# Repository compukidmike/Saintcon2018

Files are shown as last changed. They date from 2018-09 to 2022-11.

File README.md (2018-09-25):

# Saintcon2018
Here's all the info you need about the 2018 Saintcon badge. You'll find badge building and flashing instructions as well as how to operate it. The Minibadges folder has info for minibadge makers.

NOTE: Female headers will be provided with the main badge this year, so minbadge makers do not need to provide their own.

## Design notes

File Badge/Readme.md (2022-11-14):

# About the Badge
This year's badge features an ESP32 WiFi module running MicroPython. It has an 8x32 LED matrix display, 3 buttons, and 12 minibadge spots, as well as a rechargeable battery.
# Badge Instructions
## Building your badge
[BadgeBuildSheet.pdf](https://github.com/compukidmike/Saintcon2018/blob/master/Badge/BadgeBuildSheet.pdf) has instructions on how to assemble your badge
## Flashing your badge
You'll need some software to flash the code on your badge. 
The first thing you'll need is Python 3. This can be downloaded from https://www.python.org/downloads/
Once you have python installed, open a terminal/command prompt and run the following command: **pip install esptool**
You now have the tools you need to flash the code on your badge. Download **Saintcon2018.bin** from this github repository. 
Next, you will need to place the LOLIN D32 board into a mode where you can flash it's code.  To do this, you must pull GPIO pin 0 to ground.  This is best done by placing the LOLIN D32 board into a breadboard and pulling GPIO pin 0 to ground with a jumper wire.
Then, in a terminal window, navigate to the location of the badge firmware file, and run the following command, substituting the COM5 for the name of your badge serial port (this will vary depending on OS): **python esptool.py --port COM5 --baud 460800 write_flash --flash_size=detect 0 Saintcon2018.bin**

## Charging Your Badge
Simply use a microUSB cable to connect the badge to a USB power source (computer, phone charger, etc). This will power the badge as well as charge the battery.
The badge doesn't have an On/Off switch, so unplug the battery when you're not using it.

## Using Your Badge
The badge has 3 buttons labeled UP, DOWN, and SELECT. When first turned on, the badge is in display mode. Pressing the Up/Down buttons will cycle through the different displays. They are: SAINTCON, Custom Message, Hacker Challenge Score, Hacker Challenge ID.
 
Pressing Select will take you into the menu. The options here are: Brightness, Wifi Status, Wifi Config, Minibadges, Back. 
- Selecting Brightness will allow you to change the brightness of the LED matrix. 
- Selecting Wifi Status will show you if the wifi is connected or not. 
- Selecting Wifi Config will start the badge wifi configuration access point. In this mode, the display will show you the SSID and Password for the network that is being created by the badge. Connecting to that wifi network with your computer or phone will allow you to change badge settings like the wifi network that the badge connects to as well as the Custom Message. 
- Selecting Back will take you back to display mode.
 
Connecting your badge to a computer will allow you to do much more than the simple menu system allows, which brings us to...

## Editing Badge Code
To edit the badge code, I suggest an IDE called uPyCraft. It can be downloaded from http://docs.dfrobot.com/upycraft/ 
There are links on that page to tutorials on using the software.
One of the nice things about MicroPython is that the source code is all contained within the device, so you don't need to download the source to get started editing. uPyCraft can directly edit the files on the module.

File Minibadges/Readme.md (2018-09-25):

# Minibadges
The minbadge spec is here, along with eagle and kicad footprints: https://github.com/lukejenkins/minibadge  

Notes:
- 5V may not be exactly 5V. It'll probably be battery voltage (3.7-4.2V).  
- SPI *might* be connected, but don't plan on it. It gets complicated with more minibadges (one CS line per badge).  
- Please be conservative with power consumption on your minibadge. There will be a lot more minibadge spots on the badge this year, so battery life is a concern.  

If you have questions, contact me (compukidmike on twitter/slack/gmail)

## I2C Addresses
To avoid conflicts, here is the list of known minibadge I2C addresses.
To get your minibadge on this list, submit a pull request or send me a message (compukidmike on twitter/slack/gmail)
The Chip column is so I know which I2C chips to support in the main badge code (no promises, but I'm going to try to add support for as many as I can). If you're using a microcontroller, send me a spec on what I2C commands to send to it.

| Minibadge Name | Address | Chip |
| --- | --- | --- |
| hakinthebox.com | 0x01 | ATTiny |
| TBA | 0x29 | ATTiny |
| compukidmike | 0x40 | ATTiny |
| Professor Plum | 0x41 | ATTiny |
| TBA | 0x42 | ATTiny |
| TBA | 0x51 | M24C01 |
| TBA | 0x52 | M24C01 |
| bashNinja | 0x53 | M24C01 |
| TBA | 0x54 | M24C01 |

## I2C Message Protocol
This is a preliminary message protocol for minibadges. You are more than welcome to come up with other means of communication and write the supporting code for the main badge. This is just a starting point... if you have ideas on expanding this, please contact me.  

Since there isn’t an Interrupt line for the minibadges, the badge will poll each minibadge for a status byte (if supported by the minibadge).

Polling Message: 
- Will occur at regular intervals (multiple times per second) 
- Badge will send a standard read message (address with R/W bit set to R) 
- The byte that is returned by the minibadge will determine what happens next 
   - If byte is 0x00, status is empty, badge will end communication 
   - If byte is 0x01, status is Button Pressed (or similar input) (NOTE: this just passes button state to the badge. You'll have to write some code to do something with that data)
      - Next byte is button status (limited to 1 byte or 8 buttons)
   - If byte is 0x02, status is Text Message (for display on badge) (will be displayed for as long as it takes to scroll across the dislpay)
      - Next byte is text length (max 255 characters)
      - Next bytes are ASCII text
   - If byte is 0x03, status is Pixel Message (for display on badge)  (will be displayed for 2 seconds)
      - Next 32 bytes are display columns (Display is 8x32 pixels. 0,0 is bottom left corner. So first byte will fill the first column from bottom to top)
   - If byte is 0x04, status is Pixel Message with display time (this enables some animations) (for display on badge)
      - Next byte is time to display message (range is 0-255 x10 milliseconds, or 0-2.55 seconds in 10 millisecond increments). This will also be the amount of time before the badge polls the minibadge again for the next animation frame
      - Next 32 bytes are display columns (Display is 8x32 pixels. 0,0 is bottom left corner. So first byte will fill the first column from bottom to top)
   - If byte is 0x05, status is Custom Data (this allows your minibadge to send custom data to the badge that will require writing code for the badge to do something with it)
      - Next byte is length of data in bytes
      - Next bytes are custom data

Badge Event Message: 
- Will be sent to minibadges when they occur
- 0x01 - HC Score Updated
   - Next bytes(2) is score (16bit value, max score of 65535) 
- 0x02 - Brightness Change (will also be sent after power on) 
   - Next byte is brightness value (0-128) (Yes, 128. I know it's strange, but that's the brightness range for the LED matrix driver.)

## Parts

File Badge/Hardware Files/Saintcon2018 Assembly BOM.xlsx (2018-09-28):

Saintcon2018 1200PCS BOM
Click for Instructions on How to Create a BOM
Manufacturer | Manufacturer Part Number (required) | Designator (required) | Qty (required) | Description (required) | Case | SMD ,BGA,LCC,OR TH | Top/Bottom | points (number of contacts the IC has in each board) | Total points (number of contacts per BOM line has) | Comment
MCIGICM | MC-0603-RED | D1,D2,D3,D4,D5,D6,D7,D8,D9,D10,D11,D12,D13,D14,D15,D16,D17,D18,D19,D20,D21,D22,D23,D24,D25,D26,D27,D28,D29,D30,D31,D32,D33,D34,D35,D36,D37,D38,D39,D40,D41,D42,D43,D44,D45,D46,D47,D48,D49,D50,D51,D52,D53,D54,D55,D56,D57,D58,D59,D60,D61,D62,D63,D64,D65,D66,D67,D68,D69,D70,D71,D72,D73,D74,D75,D76,D77,D78,D79,D80,D81,D82,D83,D84,D85,D86,D87,D88,D89,D90,D91,D92,D93,D94,D95,D96,D97,D98,D99,D100,D101,D102,D103,D104,D105,D106,D107,D108,D109,D110,D111,D112,D113,D114,D115,D116,D117,D118,D119,D120,D121,D122,D123,D124,D125,D126,D127,D128,D129,D130,D131,D132,D133,D134,D135,D136,D137,D138,D139,D140,D141,D142,D143,D144,D145,D146,D147,D148,D149,D150,D151,D152,D153,D154,D155,D156,D157,D158,D159,D160,D161,D162,D163,D164,D165,D166,D167,D168,D169,D170,D171,D172,D173,D174,D175,D176,D177,D178,D179,D180,D181,D182,D183,D184,D185,D186,D187,D188,D189,D190,D191,D192,D193,D194,D195,D196,D197,D198,D199,D200,D201,D202,D203,D204,D205,D206,D207,D208,D209,D210,D211,D212,D213,D214,D215,D216,D217,D218,D219,D220,D221,D222,D223,D224,D225,D226,D227,D228,D229,D230,D231,D232,D233,D234,D235,D236,D237,D238,D239,D240,D241,D242,D243,D244,D245,D246,D247,D248,D249,D250,D251,D252,D253,D254,D255,D256 | 256 | Red LED 0603 | 0603 | SMD | Top | 2 | 512
ISSI | IS31FL3730-QFLS2-TR | U2,U3 | 2 | IC MATRIX LED DRIVER AUDIO 24QFN | QFN24 | SMD | Top | 24 | 48
Samsung Electro-Mechanics | CL10A105KP8NNNC | C1,C2,C9,C12,C13 | 5 | CAP CER 1UF 10V X5R 0603 | 0603 | SMD | Top | 2 | 10 | Generic Substitue is OK
Samsung Electro-Mechanics | CL10B104KB8NNNC | C3,C4,C10 | 3 | CAP CER 0.1UF 50V X7R 0603 | 0603 | SMD | Top | 2 | 6 | Generic Substitue is OK
Nichion | UWR1A101MCL1GB | C11 | 1 | CAP ALUM 100UF 20% 10V SMD | Radial, Can - SMD | SMD | Top | 2 | 2
Yaego | RC0603JR-07100KL | R3,R6,R7 | 3 | RES SMD 100K OHM 5% 1/10W 0603 | 0603 | SMD | Top | 2 | 6 | Generic Substitue is OK
Yaego | RC0603JR-074K7L | R1,R2,R4,R5 | 4 | RES SMD 4.7K OHM 5% 1/10W 0603 | 0603 | SMD | Top | 2 | 8 | Generic Substitue is OK
Diodes Incorporated | AP22802AW5-7 | U4 | 1 | IC LOAD SW PROGR SOT-25 | SC-74A, SOT-753 | SMD | Top | 5 | 5
Diodes Incorporated | AP2112K-3.3TRG1 | U5 | 1 | IC REG LINEAR 3.3V 600MA SOT25 | SC-74A, SOT-753 | SMD | Top | 5 | 5
C&K | PTS645SM43SMTR92 LFS | SW1,SW2,SW3 | 3 | SWITCH TACTILE SPST-NO 0.05A 12V | Gull Wing | SMD | Top | 4 | 12
DO NOT POPULATE | DO NOT POPULATE | J7,J6,J1,J2,J3,J4,J5,J8,J9,J10,J11,J12 | 12 | DO NOT POPULATE | DO NOT POPULATE | DO NOT POPULATE | Top | 0 | 0
DO NOT POPULATE | DO NOT POPULATE | U1 | 1 | DO NOT POPULATE | DO NOT POPULATE | DO NOT POPULATE | Top | 0 | 0

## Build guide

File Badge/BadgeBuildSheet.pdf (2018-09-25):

# Saintcon 2018 Badge Build Instructions

Most of the badge parts have already been soldered for you. The only things you need to solder are the headers for the main controller and the minibadges.

Step 1: Pick your headers. The HHC has 5 colors to choose from, so mix and match to make your badge uniquely yours! Available colors are: Red, Green, Blue, Yellow, and Black.
Step 2: Place headers on the Header Soldering Jig. This jig will hold all the headers straight to make it easier for you to solder your badge. Place your badge face-down on the headers and solder them all.

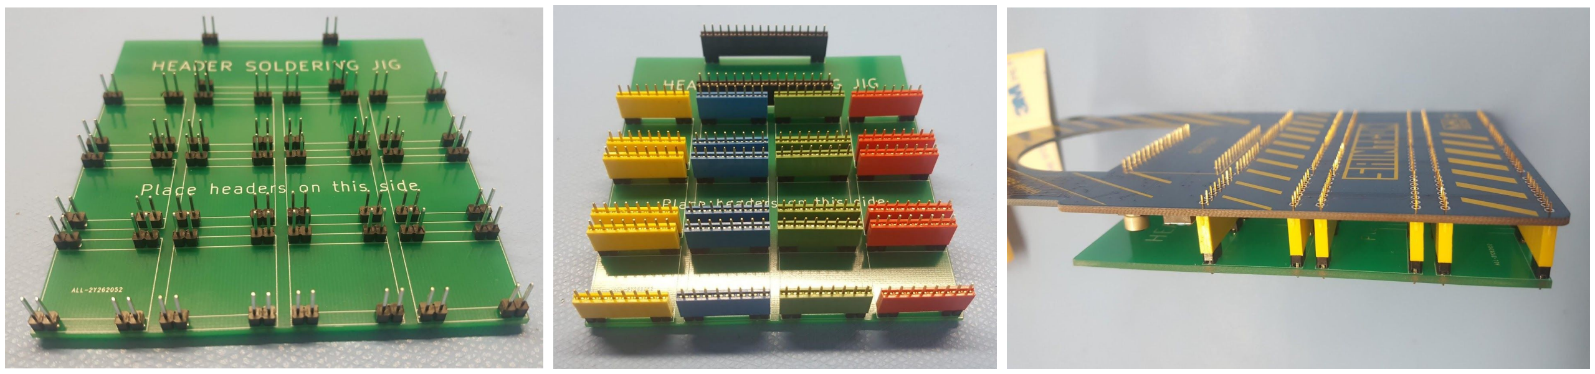
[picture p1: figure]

Step 3: Solder the ESP32. The module comes with 2 16pin headers. Plug them into the headers on the front of your board and then put the ESP32 on top. Pay close attention to orientation of the module. There are markings on the badge that you can match up to the module. Solder all the pins on the ESP32.

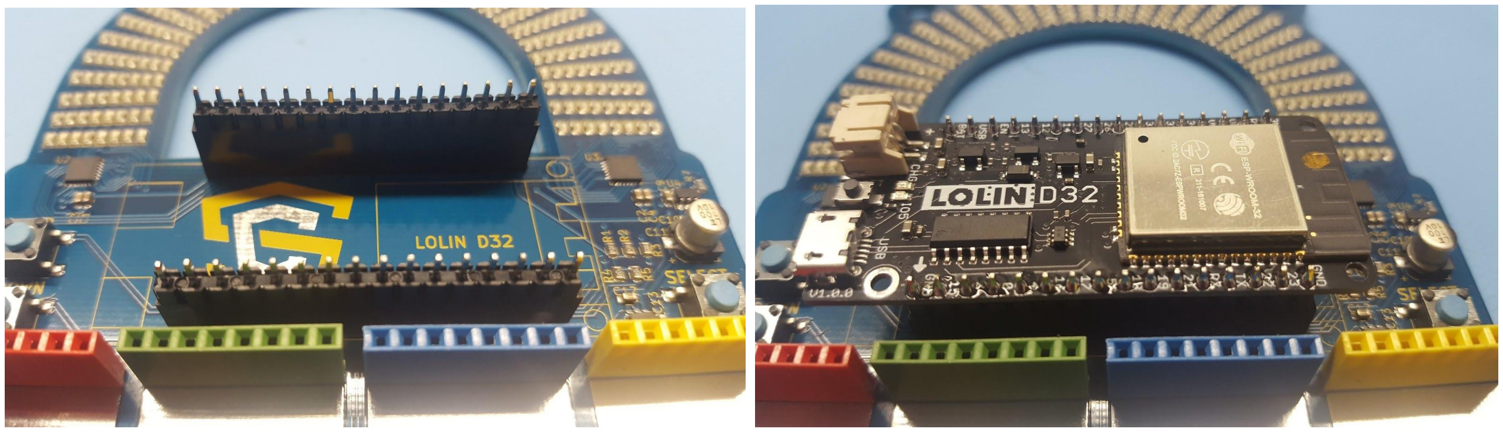
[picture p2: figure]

Step 4: Attach the plastic back plate. Remove the paper covering from both sides of the plastic. Test-fit it on the back of the badge. It can only fit one way, so if it doesn’t fit, try flipping it over. Now grab a couple strips of double-sided tape and stick the plastic sheet to the back of the badge.

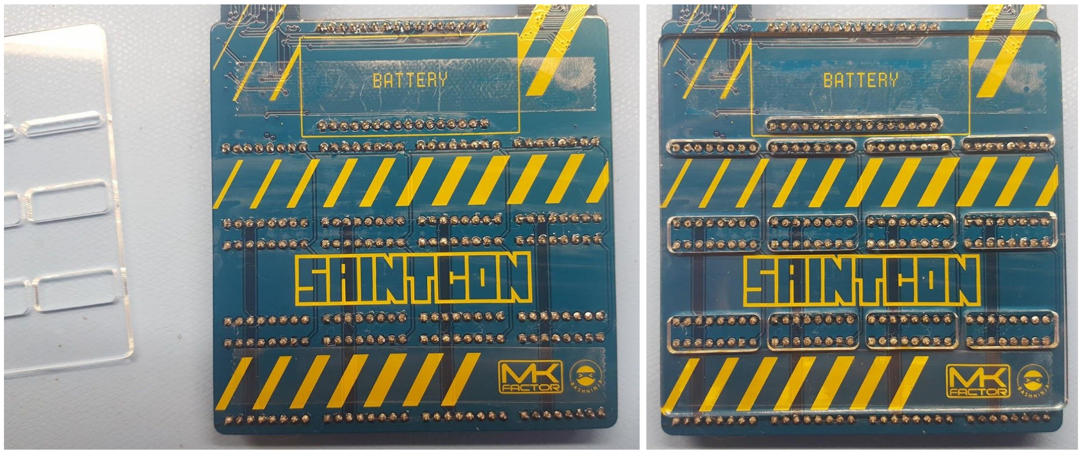
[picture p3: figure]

Step 5: Mount the battery. Using the sticky pad in your kit, attach the battery to the back of the badge, making sure the connector comes out the top-right corner of the battery.

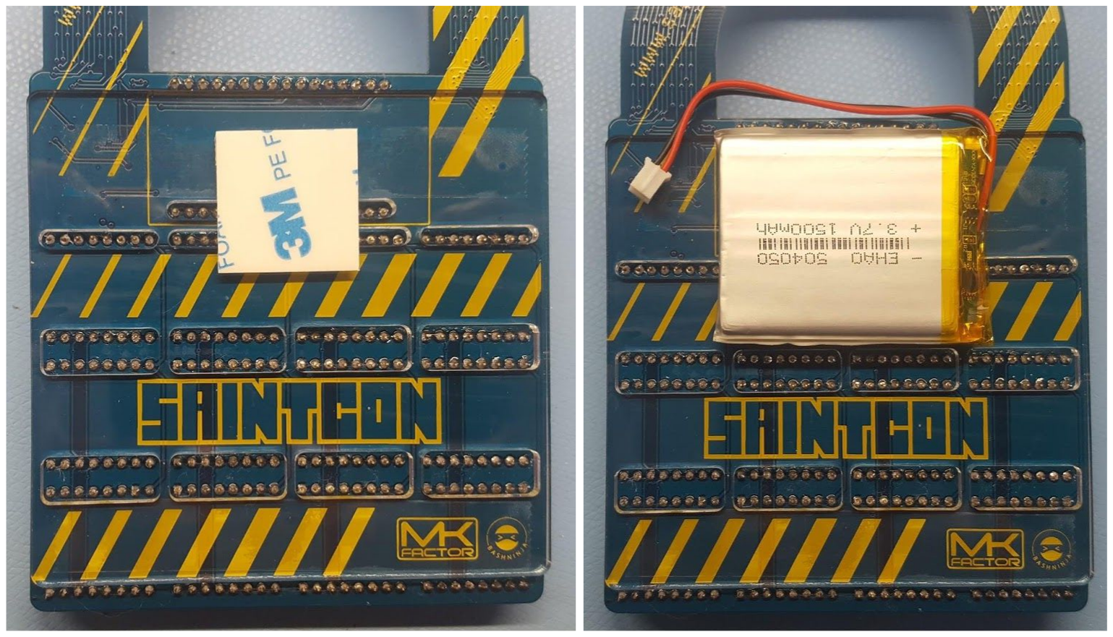
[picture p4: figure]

Step 6: Connect the battery. If all went well, your badge should light up! If it doesn’t, there are lots of talented staff members at the HHC that can help you out.

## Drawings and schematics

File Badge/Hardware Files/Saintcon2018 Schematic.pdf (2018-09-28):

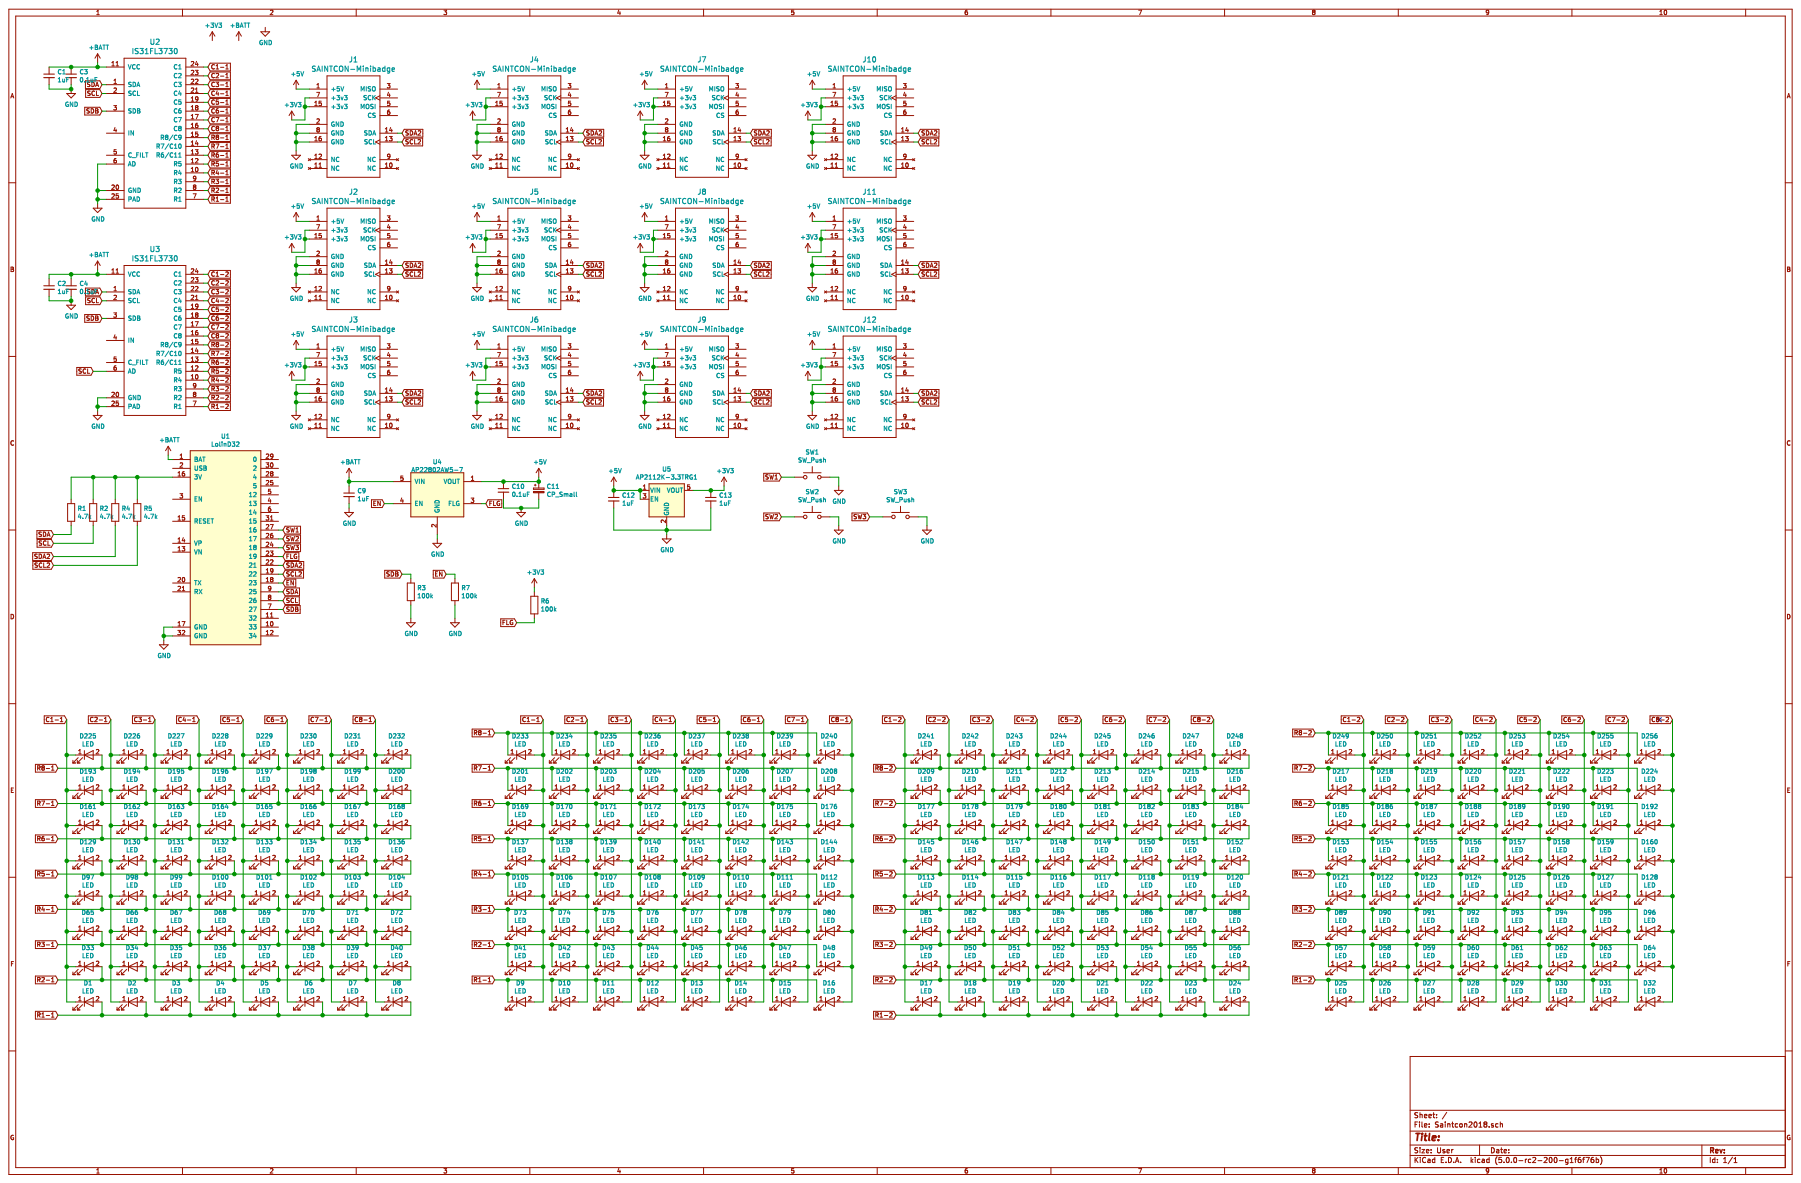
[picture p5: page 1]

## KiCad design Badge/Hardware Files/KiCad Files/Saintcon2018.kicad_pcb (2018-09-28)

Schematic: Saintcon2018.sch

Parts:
C1, C2, C9, C12, C13: 1uF; C_0603
C3, C4, C10: 0.1uF; C_0603
C11: CP_Small; CP_Elec_5x5.3
D1, D2, D3, D4, D5, D6, D7, D8, D9, D10, D11, D12, D13, D14, D15, D16, D17, D18, D19, D20, D21, D22, D23, D24, D25, D26, D27, D28, D29, D30, D31, D32, D33, D34, D35, D36, D37, D38, D39, D40, D41, D42, D43, D44, D45, D46, D47, D48, D49, D50, D51, D52, D53, D54, D55, D56, D57, D58, D59, D60, D61, D62, D63, D64, D65, D66, D67, D68, D69, D70, D71, D72, D73, D74, D75, D76, D77, D78, D79, D80, D81, D82, D83, D84, D85, D86, D87, D88, D89, D90, D91, D92, D93, D94, D95, D96, D97, D98, D99, D100, D101, D102, D103, D104, D105, D106, D107, D108, D109, D110, D111, D112, D113, D114, D115, D116, D117, D118, D119, D120, D121, D122, D123, D124, D125, D126, D127, D128, D129, D130, D131, D132, D133, D134, D135, D136, D137, D138, D139, D140, D141, D142, D143, D144, D145, D146, D147, D148, D149, D150, D151, D152, D153, D154, D155, D156, D157, D158, D159, D160, D161, D162, D163, D164, D165, D166, D167, D168, D169, D170, D171, D172, D173, D174, D175, D176, D177, D178, D179, D180, D181, D182, D183, D184, D185, D186, D187, D188, D189, D190, D191, D192, D193, D194, D195, D196, D197, D198, D199, D200, D201, D202, D203, D204, D205, D206, D207, D208, D209, D210, D211, D212, D213, D214, D215, D216, D217, D218, D219, D220, D221, D222, D223, D224, D225, D226, D227, D228, D229, D230, D231, D232, D233, D234, D235, D236, D237, D238, D239, D240, D241, D242, D243, D244, D245, D246, D247, D248, D249, D250, D251, D252, D253, D254, D255, D256: LED; LED_0603_1608Metric
J1, J2, J3, J4, J5, J6, J7, J8, J9, J10, J11, J12: SAINTCON-Minibadge; SAINTCON-Minibadge-Shiny
R1, R2, R4, R5: 4.7k; R_0603
R3, R6, R7: 100k; R_0603
SW1, SW2, SW3: SW_Push; SW_SPST_PTS645
U1: LolinD32; Lolin D32
U2, U3: IS31FL3730; QFN-24_EP_4x4_Pitch0.5mm
U4: AP22802AW5-7; SOT-23-5
U5: AP2112K-3.3TRG1; SOT-23-5

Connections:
+3V3: C13.1, J1.7, J1.15, J2.7, J2.15, J3.7, J3.15, J4.7, J4.15, J5.7, J5.15, J6.7, J6.15, J7.7, J7.15, J8.7, J8.15, J9.7, J9.15, J10.7, J10.15, J11.7, J11.15, J12.7, J12.15, R6.1, U5.5 (VOUT)
+5V: C10.1, C11.1, C12.1, J1.1, J2.1, J3.1, J4.1, J5.1, J6.1, J7.1, J8.1, J9.1, J10.1, J11.1, J12.1, U4.1 (VOUT), U5.1 (VIN), U5.3 (EN)
+BATT: C1.1, C2.1, C3.1, C4.1, C9.1, U1.1 (BAT), U2.11 (VCC), U3.11 (VCC), U4.5 (VIN)
C1-1: D1.1 (K), D9.2 (A), D33.1 (K), D41.2 (A), D65.1 (K), D73.2 (A), D97.1 (K), D105.2 (A), D129.1 (K), D137.2 (A), D161.1 (K), D169.2 (A), D193.1 (K), D201.2 (A), D225.1 (K), D233.2 (A), U2.24 (C1)
C1-2: D17.1 (K), D25.2 (A), D49.1 (K), D57.2 (A), D81.1 (K), D89.2 (A), D113.1 (K), D121.2 (A), D145.1 (K), D153.2 (A), D177.1 (K), D185.2 (A), D209.1 (K), D217.2 (A), D241.1 (K), D249.2 (A), U3.24 (C1)
C2-1: D2.1 (K), D10.2 (A), D34.1 (K), D42.2 (A), D66.1 (K), D74.2 (A), D98.1 (K), D106.2 (A), D130.1 (K), D138.2 (A), D162.1 (K), D170.2 (A), D194.1 (K), D202.2 (A), D226.1 (K), D234.2 (A), U2.23 (C2)
C2-2: D18.1 (K), D26.2 (A), D50.1 (K), D58.2 (A), D82.1 (K), D90.2 (A), D114.1 (K), D122.2 (A), D146.1 (K), D154.2 (A), D178.1 (K), D186.2 (A), D210.1 (K), D218.2 (A), D242.1 (K), D250.2 (A), U3.23 (C2)
C3-1: D3.1 (K), D11.2 (A), D35.1 (K), D43.2 (A), D67.1 (K), D75.2 (A), D99.1 (K), D107.2 (A), D131.1 (K), D139.2 (A), D163.1 (K), D171.2 (A), D195.1 (K), D203.2 (A), D227.1 (K), D235.2 (A), U2.22 (C3)
C3-2: D19.1 (K), D27.2 (A), D51.1 (K), D59.2 (A), D83.1 (K), D91.2 (A), D115.1 (K), D123.2 (A), D147.1 (K), D155.2 (A), D179.1 (K), D187.2 (A), D211.1 (K), D219.2 (A), D243.1 (K), D251.2 (A), U3.22 (C3)
C4-1: D4.1 (K), D12.2 (A), D36.1 (K), D44.2 (A), D68.1 (K), D76.2 (A), D100.1 (K), D108.2 (A), D132.1 (K), D140.2 (A), D164.1 (K), D172.2 (A), D196.1 (K), D204.2 (A), D228.1 (K), D236.2 (A), U2.21 (C4)
C4-2: D20.1 (K), D28.2 (A), D52.1 (K), D60.2 (A), D84.1 (K), D92.2 (A), D116.1 (K), D124.2 (A), D148.1 (K), D156.2 (A), D180.1 (K), D188.2 (A), D212.1 (K), D220.2 (A), D244.1 (K), D252.2 (A), U3.21 (C4)
C5-1: D5.1 (K), D13.2 (A), D37.1 (K), D45.2 (A), D69.1 (K), D77.2 (A), D101.1 (K), D109.2 (A), D133.1 (K), D141.2 (A), D165.1 (K), D173.2 (A), D197.1 (K), D205.2 (A), D229.1 (K), D237.2 (A), U2.19 (C5)
C5-2: D21.1 (K), D29.2 (A), D53.1 (K), D61.2 (A), D85.1 (K), D93.2 (A), D117.1 (K), D125.2 (A), D149.1 (K), D157.2 (A), D181.1 (K), D189.2 (A), D213.1 (K), D221.2 (A), D245.1 (K), D253.2 (A), U3.19 (C5)
C6-1: D6.1 (K), D14.2 (A), D38.1 (K), D46.2 (A), D70.1 (K), D78.2 (A), D102.1 (K), D110.2 (A), D134.1 (K), D142.2 (A), D166.1 (K), D174.2 (A), D198.1 (K), D206.2 (A), D230.1 (K), D238.2 (A), U2.18 (C6)
C6-2: D22.1 (K), D30.2 (A), D54.1 (K), D62.2 (A), D86.1 (K), D94.2 (A), D118.1 (K), D126.2 (A), D150.1 (K), D158.2 (A), D182.1 (K), D190.2 (A), D214.1 (K), D222.2 (A), D246.1 (K), D254.2 (A), U3.18 (C6)
C7-1: D7.1 (K), D15.2 (A), D39.1 (K), D47.2 (A), D71.1 (K), D79.2 (A), D103.1 (K), D111.2 (A), D135.1 (K), D143.2 (A), D167.1 (K), D175.2 (A), D199.1 (K), D207.2 (A), D231.1 (K), D239.2 (A), U2.17 (C7)
C7-2: D23.1 (K), D31.2 (A), D55.1 (K), D63.2 (A), D87.1 (K), D95.2 (A), D119.1 (K), D127.2 (A), D151.1 (K), D159.2 (A), D183.1 (K), D191.2 (A), D215.1 (K), D223.2 (A), D247.1 (K), D255.2 (A), U3.17 (C7)
C8-1: D8.1 (K), D16.2 (A), D40.1 (K), D48.2 (A), D72.1 (K), D80.2 (A), D104.1 (K), D112.2 (A), D136.1 (K), D144.2 (A), D168.1 (K), D176.2 (A), D200.1 (K), D208.2 (A), D232.1 (K), D240.2 (A), U2.16 (C8)
C8-2: D24.1 (K), D32.2 (A), D56.1 (K), D64.2 (A), D88.1 (K), D96.2 (A), D120.1 (K), D128.2 (A), D152.1 (K), D160.2 (A), D184.1 (K), D192.2 (A), D216.1 (K), D224.2 (A), D248.1 (K), D256.2 (A), U3.16 (C8)
EN: R7.1, U1.18 (23), U4.4 (EN)
FLG: R6.2, U1.23 (19), U4.3 (FLG)
GND: C1.2, C2.2, C3.2, C4.2, C9.2, C10.2, C11.2, C12.2, C13.2, J1.2, J1.8, J1.16, J2.2, J2.8, J2.16, J3.2, J3.8, J3.16, J4.2, J4.8, J4.16, J5.2, J5.8, J5.16, J6.2, J6.8, J6.16, J7.2, J7.8, J7.16, J8.2, J8.8, J8.16, J9.2, J9.8, J9.16, J10.2, J10.8, J10.16, J11.2, J11.8, J11.16, J12.2, J12.8, J12.16, R3.2, R7.2, SW1.2, SW2.2, SW3.2, U1.17 (GND), U1.32 (GND), U2.6 (AD), U2.20 (GND), U2.25 (PAD), U3.20 (GND), U3.25 (PAD), U4.2 (GND), U5.2 (GND)
unnamed: R1.1, R2.1, R4.1, R5.1, U1.16 (3V)
R1-1: D1.2 (A), D2.2 (A), D3.2 (A), D4.2 (A), D5.2 (A), D6.2 (A), D7.2 (A), D8.2 (A), D9.1 (K), D10.1 (K), D11.1 (K), D12.1 (K), D13.1 (K), D14.1 (K), D15.1 (K), D16.1 (K), U2.7 (R1)
R1-2: D17.2 (A), D18.2 (A), D19.2 (A), D20.2 (A), D21.2 (A), D22.2 (A), D23.2 (A), D24.2 (A), D25.1 (K), D26.1 (K), D27.1 (K), D28.1 (K), D29.1 (K), D30.1 (K), D31.1 (K), D32.1 (K), U3.7 (R1)
R2-1: D33.2 (A), D34.2 (A), D35.2 (A), D36.2 (A), D37.2 (A), D38.2 (A), D39.2 (A), D40.2 (A), D41.1 (K), D42.1 (K), D43.1 (K), D44.1 (K), D45.1 (K), D46.1 (K), D47.1 (K), D48.1 (K), U2.8 (R2)
R2-2: D49.2 (A), D50.2 (A), D51.2 (A), D52.2 (A), D53.2 (A), D54.2 (A), D55.2 (A), D56.2 (A), D57.1 (K), D58.1 (K), D59.1 (K), D60.1 (K), D61.1 (K), D62.1 (K), D63.1 (K), D64.1 (K), U3.8 (R2)
R3-1: D65.2 (A), D66.2 (A), D67.2 (A), D68.2 (A), D69.2 (A), D70.2 (A), D71.2 (A), D72.2 (A), D73.1 (K), D74.1 (K), D75.1 (K), D76.1 (K), D77.1 (K), D78.1 (K), D79.1 (K), D80.1 (K), U2.9 (R3)
R3-2: D81.2 (A), D82.2 (A), D83.2 (A), D84.2 (A), D85.2 (A), D86.2 (A), D87.2 (A), D88.2 (A), D89.1 (K), D90.1 (K), D91.1 (K), D92.1 (K), D93.1 (K), D94.1 (K), D95.1 (K), D96.1 (K), U3.9 (R3)
R4-1: D97.2 (A), D98.2 (A), D99.2 (A), D100.2 (A), D101.2 (A), D102.2 (A), D103.2 (A), D104.2 (A), D105.1 (K), D106.1 (K), D107.1 (K), D108.1 (K), D109.1 (K), D110.1 (K), D111.1 (K), D112.1 (K), U2.10 (R4)
R4-2: D113.2 (A), D114.2 (A), D115.2 (A), D116.2 (A), D117.2 (A), D118.2 (A), D119.2 (A), D120.2 (A), D121.1 (K), D122.1 (K), D123.1 (K), D124.1 (K), D125.1 (K), D126.1 (K), D127.1 (K), D128.1 (K), U3.10 (R4)
R5-1: D129.2 (A), D130.2 (A), D131.2 (A), D132.2 (A), D133.2 (A), D134.2 (A), D135.2 (A), D136.2 (A), D137.1 (K), D138.1 (K), D139.1 (K), D140.1 (K), D141.1 (K), D142.1 (K), D143.1 (K), D144.1 (K), U2.12 (R5)
R5-2: D145.2 (A), D146.2 (A), D147.2 (A), D148.2 (A), D149.2 (A), D150.2 (A), D151.2 (A), D152.2 (A), D153.1 (K), D154.1 (K), D155.1 (K), D156.1 (K), D157.1 (K), D158.1 (K), D159.1 (K), D160.1 (K), U3.12 (R5)
R6-1: D161.2 (A), D162.2 (A), D163.2 (A), D164.2 (A), D165.2 (A), D166.2 (A), D167.2 (A), D168.2 (A), D169.1 (K), D170.1 (K), D171.1 (K), D172.1 (K), D173.1 (K), D174.1 (K), D175.1 (K), D176.1 (K), U2.13 (R6/C11)
R6-2: D177.2 (A), D178.2 (A), D179.2 (A), D180.2 (A), D181.2 (A), D182.2 (A), D183.2 (A), D184.2 (A), D185.1 (K), D186.1 (K), D187.1 (K), D188.1 (K), D189.1 (K), D190.1 (K), D191.1 (K), D192.1 (K), U3.13 (R6/C11)
R7-1: D193.2 (A), D194.2 (A), D195.2 (A), D196.2 (A), D197.2 (A), D198.2 (A), D199.2 (A), D200.2 (A), D201.1 (K), D202.1 (K), D203.1 (K), D204.1 (K), D205.1 (K), D206.1 (K), D207.1 (K), D208.1 (K), U2.14 (R7/C10)
R7-2: D209.2 (A), D210.2 (A), D211.2 (A), D212.2 (A), D213.2 (A), D214.2 (A), D215.2 (A), D216.2 (A), D217.1 (K), D218.1 (K), D219.1 (K), D220.1 (K), D221.1 (K), D222.1 (K), D223.1 (K), D224.1 (K), U3.14 (R7/C10)
R8-1: D225.2 (A), D226.2 (A), D227.2 (A), D228.2 (A), D229.2 (A), D230.2 (A), D231.2 (A), D232.2 (A), D233.1 (K), D234.1 (K), D235.1 (K), D236.1 (K), D237.1 (K), D238.1 (K), D239.1 (K), D240.1 (K), U2.15 (R8/C9)
R8-2: D241.2 (A), D242.2 (A), D243.2 (A), D244.2 (A), D245.2 (A), D246.2 (A), D247.2 (A), D248.2 (A), D249.1 (K), D250.1 (K), D251.1 (K), D252.1 (K), D253.1 (K), D254.1 (K), D255.1 (K), D256.1 (K), U3.15 (R8/C9)
SCL: R2.2, U1.8 (26), U2.2 (SCL), U3.2 (SCL), U3.6 (AD)
SCL2: J1.13, J2.13, J3.13, J4.13, J5.13, J6.13, J7.13, J8.13, J9.13, J10.13, J11.13, J12.13, R5.2, U1.19 (22)
SDA: R1.2, U1.9 (25), U2.1 (SDA), U3.1 (SDA)
SDA2: J1.14, J2.14, J3.14, J4.14, J5.14, J6.14, J7.14, J8.14, J9.14, J10.14, J11.14, J12.14, R4.2, U1.22 (21)
SDB: R3.1, U1.7 (27), U2.3 (SDB), U3.3 (SDB)
SW1: SW1.1, U1.27 (16)
SW2: SW2.1, U1.26 (17)
SW3: SW3.1, U1.24 (18)

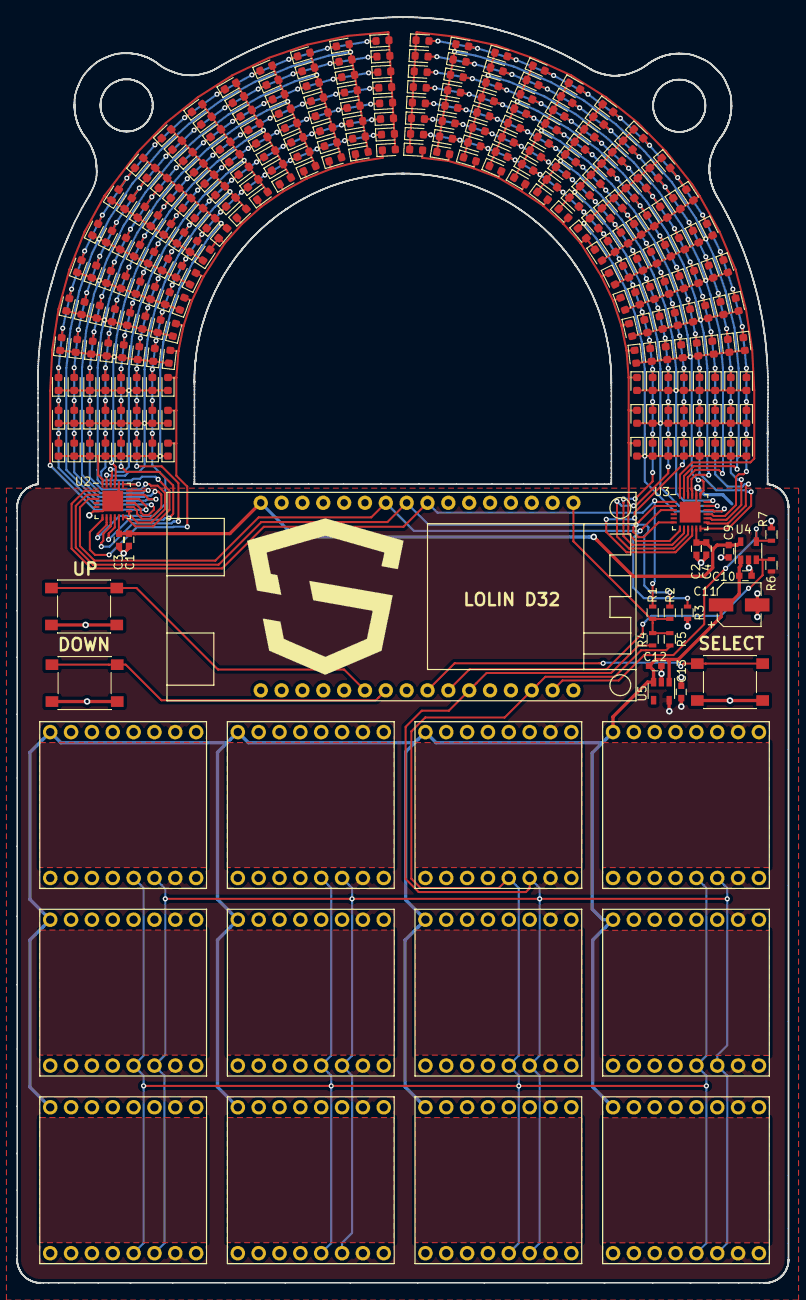
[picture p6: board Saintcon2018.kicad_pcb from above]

Board: 2 copper layers, 94.0 x 154.2 mm, 292 parts (0 on the bottom side), 47 nets.

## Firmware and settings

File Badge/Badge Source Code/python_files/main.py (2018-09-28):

#Saintcon2018 Badge Code
#by compukidmike and bashninja

#hardware platform: ESP32

import time
import machine
import matrix
import uasyncio as asyncio
from aswitch import Pushbutton

import configure
import wifi_config
import hc
import hcid as HCID

import _thread

hcid = HCID.getHCID()

hcidPassword = HCID.getPassword()

wifiConfigMode = 0
wifiMacAddr = HCID.getMac()
print("MAC Address: " + wifiMacAddr)
wifiConfigSSID = "SC_" + str(wifiMacAddr)[-5:-1]

ssid = ""


i2c = machine.I2C(scl=machine.Pin(26), sda=machine.Pin(25), freq=100000)
i2c2 = machine.I2C(scl=machine.Pin(22), sda=machine.Pin(21), freq=10000)

#Add minibadge I2C addresses to this list
I2CDeviceList = {0x01,0x29,0x40, 0x41, 0x42}
#I2CDeviceList = {0x01,0x40}
#Add minibadges with I2C EEPROMs to this list
I2CEEPROMList = {}

led = matrix.Matrix(i2c)
brightness = 32
displayUpdateDelay = 75
nextDisplayUpdateTime = 0
currentTicks = 0
animationCounter = 0

upPressed = 0
downPressed = 0
selectPressed = 0

displayState = 1
previousDisplayState = 1
displayMode = 0
currentAnimation = 0

userHandle = 'Test'
userHCScore = 0
userCustomMessage = 'Custom Message'

minibadgePreviousDisplayState = 0
minibadgeTextMessage = 'empty'
pixelDisplayData = bytearray(32)
pixelDisplayDelay = 2000


pwrEnable = machine.Pin(23, machine.Pin.OUT)
pwrEnable.value(1) #Turn on minbadge power

displayEnable = machine.Pin(27, machine.Pin.OUT)
displayEnable.value(1) #Enable matrix drivers

upPin = machine.Pin(16, machine.Pin.IN, machine.Pin.PULL_UP)
downPin = machine.Pin(17, machine.Pin.IN, machine.Pin.PULL_UP)
selectPin = machine.Pin(18, machine.Pin.IN, machine.Pin.PULL_UP)

#set LED matrix brightness
led.brightness(brightness)

#Send brightness to all minibadges
data = bytearray(3)
for x in I2CDeviceList:
  if x != 0x01:
    try:
      i2c2.start()
      data[0] = x<<1 
      data[1] = 0x02
      data[2] = brightness
      i2c2.write(data)
      i2c2.stop()
    except:
      pass
#print(i2c2.scan()) #Use this to debug I2C stuff


async def buttonPressed(button): #up=1,down=2,select=3
  global displayState
  if displayState != 18 and displayState != 19:
    switcher = {
      1: stateSaintcon,
      2: stateCustom,
      3: stateHCScore,
      4: stateHCID,
      5: stateBroadcast,
      6: stateMenuBrightness,
      7: stateMenuHandleEdit,
      8: stateMenuWifiStatus,
      9: stateMenuWifiConfig,
      10: stateMenuMinibadges,
      12: stateMenuBack,
      13: stateBrightness,
      14: stateHandleEdit,
      15: stateWifiStatus,
      16: stateWifiConfig,
      17: stateMinibadges
    }
    func = switcher.get(displayState)
    result = func(button)
    #print("state:", displayState)
  
  
def stateSaintcon(button): #1
  global displayState
  global userCustomMessage
  if(button == 1): #Up Button
    userCustomMessage = wifi_config.get_custom_message()
    displayState = 4 #Custom
  if(button == 2): #Down Button
    displayState = 2 #Handle
  if(button == 3): #Select Button
    displayState = 6 #MenuBrightness
    
def stateCustom(button): #2
  global displayState
  if(button == 1): #Up Button
    displayState = 1 #Saintcon
  if(button == 2): #Down Button
    displayState = 3 #HCScore
  if(button == 3): #Select Button
    displayState = 6 #MenuBrightness
    
def stateHCScore(button): #3
  global displayState
  global userCustomMessage
  if(button == 1): #Up Button
    displayState = 2 #Handle
  if(button == 2): #Down Button
    userCustomMessage = wifi_config.get_custom_message()
    displayState = 4 #Custom
  if(button == 3): #Select Button
    displayState = 6 #MenuBrightness
    
def stateHCID(button): #4
  global displayState
  if(button == 1): #Up Button
    displayState = 3 #HCScore
  if(button == 2): #Down Button
    displayState = 1 #Saintcon
  if(button == 3): #Select Button
    displayState = 6 #MenuBrightness
    
def stateBroadcast(button): #5
  global displayState
  global userCustomMessage
  if(button == 1): #Up Button
    userCustomMessage = wifi_config.get_custom_message()
    displayState = 4 #Custom
  if(button == 2): #Down Button
    displayState = 2 #Handle
  if(button == 3): #Select Button
    displayState = 6 #MenuBrightness
    
def stateMenuBrightness(button): #6
  global displayState
  if(button == 1): #Up Button
    displayState = 12 #MenuBack
  if(button == 2): #Down Button
    displayState = 8 #MenuHandleEdit
  if(button == 3): #Select Button
    displayState = 13 #Brightness

def stateMenuHandleEdit(button): #7
  #not implemented
  return

def stateMenuWifiStatus(button): #8
  global displayState
  global ssid
  if(button == 1): #Up Button
    displayState = 6 #MenuHandleEdit
  if(button == 2): #Down Button
    displayState = 9 #MenuWifiConfig
  if(button == 3): #Select Button
    ssid = wifi_config.get_ssid()
    displayState = 15 #WifiStatus
    
def stateMenuWifiConfig(button): #9
  global displayState
  global wifiConfigMode
  if(button == 1): #Up Button
    displayState = 8 #MenuWifiStatus
  if(button == 2): #Down Button
    displayState = 10 #MenuMinibadges
  if(button == 3): #Select Button
    displayState = 16 #WifiConfig
    wifiConfigMode = 1
    
def stateMenuMinibadges(button): #10
  global displayState
  if(button == 1): #Up Button
    displayState = 9 #MenuWifiConfig
  if(button == 2): #Down Button
    displayState = 12 #MenuBrightness
  if(button == 3): #Select Button
    displayState = 17 #Minibadges
    
def stateMenuBack(button): #12
  global displayState
  if(button == 1): #Up Button
    displayState = 10 #MenuMinibadges
  if(button == 2): #Down Button
    displayState = 6 #MenuBrightness
  if(button == 3): #Select Button
    displayState = 1 #Saintcon
    
def stateBrightness(button): #13
  global displayState
  global brightness
  if(button == 1): #Up Button
    brightness += 10
    if(brightness > 128):
      brightness = 128
  if(button == 2): #Down Button
    brightness -= 10
    if(brightness < 1):
      brightness = 1
  led.brightness(brightness)
  data = bytearray(3)
  for x in I2CDeviceList:
    if x != 0x01:
      try:
        i2c2.start()
        data[0] = x<<1 
        data[1] = 0x02
        data[2] = brightness
        i2c2.write(data)
        i2c2.stop()
      except:
        pass
  if(button == 3): #Select Button
    displayState = 6 #MenuBrightness
    
def stateHandleEdit(button): #14
  #not implemented
  return
    
def stateWifiStatus(button): #15
  global displayState
  if(button == 3): #Select Button
    displayState = 8 #MenuWifiStatus
    
def stateWifiConfig(button): #16
  global displayState
  if(button == 1): #Up Button
    displayState = 16
  if(button == 2): #Down Button
    displayState = 16
  if(button == 3): #Select Button
    displayState = 16 #MenuWifiConfig

def stateMinibadges(button): #17
  global displayState
  global displayEnable
  if(button == 1): #Up Button
    if(pwrEnable.value() == 1):
      pwrEnable.value(0)
    else:
      pwrEnable.value(1)
  if(button == 2): #Down Button
    if(pwrEnable.value() == 1):
      pwrEnable.value(0)
    else:
      pwrEnable.value(1)
  if(button == 3): #Select Button
    displayState = 10 #MenuMinibadges
    

async def updateDisplay():
  global animationCounter
  global scrollCounter
  global displayUpdateDelay
  global displayState
  global previousDisplayState
  global userHandle
  global userHCScore
  global userCustomMessage
  global minibadgeTextMessage
  global minibadgePreviousDisplayState
  global pixelDisplayData
  global pixelDisplayDelay
  global ssid
  
  while(True):
    if(previousDisplayState != displayState):
      previousDisplayState = displayState
      animationCounter = 0
    
    if(displayState == 1): #Saintcon
      animationCounter += 1
      if(animationCounter > 80):
        animationCounter = 0
      led.word("SAINTCON",32-animationCounter)
      
    
    if(displayState == 2): #Custom
      if((len(str(userCustomMessage)) * 6)-1 > 32):
        animationCounter += 1
        if(animationCounter > (len(str(userCustomMessage)) * 6)+32):
          animationCounter = 0
        led.word(str(userCustomMessage),32-animationCounter)
      else:
        led.word(str(userCustomMessage), int((32-(len(str(userCustomMessage))*6))/2))
        

    if(displayState == 3): #HCScore
      if((len(str(userHCScore)) * 6)-1 > 32):
        animationCounter += 1
        if(animationCounter > (len(str(userHCScore)) * 6)+32):
          animationCounter = 0
        led.word(str(userHCScore),32-animationCounter)
      else:
        led.word(str(userHCScore), int((32-(len(str(userHCScore))*6))/2))
        
    if(displayState == 4): #HCID
      message = "HCID: " + hcid
      if((len(message) * 6)-1 > 32):
        animationCounter += 1
        if(animationCounter > (len(message) * 6)+32):
          animationCounter = 0
        led.word(message,32-animationCounter)
      else:
        led.word(message, int((32-(len(message)*6))/2))
    
    #if(displayState == 5): #Broadcast
      #do something

    
    if(displayState == 6): #MenuBrightness
      animationCounter += 1
      if(animationCounter > (len("BRIGHTNESS") * 6)+32):
        animationCounter = 0
      led.word("BRIGHTNESS",32-animationCounter)
    
    if(displayState == 7): #MenuHandleEdit
      animationCounter += 1
      if(animationCounter > (len("HANDLE EDIT") * 6)+32):
        animationCounter = 0
      led.word("HANDLE EDIT",32-animationCounter)
    
    if(displayState == 8): #MenuWifiStatus
      animationCounter += 1
      if(animationCounter > (len("WIFI STATUS") * 6)+32):
        animationCounter = 0
      led.word("WIFI STATUS",32-animationCounter)
    
    if(displayState == 9): #MenuWifiConfig
      animationCounter += 1
      if(animationCounter > (len("WIFI CONFIG") * 6)+32):
        animationCounter = 0
      led.word("WIFI CONFIG",32-animationCounter)
    
    if(displayState == 10): #MenuMinibadges
      animationCounter += 1
      if(animationCounter > (len("MINIBADGES") * 6)+32):
        animationCounter = 0
      led.word("MINIBADGES",32-animationCounter)
    
    if(displayState == 12): #MenuBack
      animationCounter += 1
      if(animationCounter > (len("BACK") * 6)+32):
        animationCounter = 0
      led.word("BACK",32-animationCounter)
    
    if(displayState == 13): #Brightness
      global brightness
      led.word(str(brightness), int((32-(len(str(brightness))*6))/2))
    
    if(displayState == 14): #HandleEdit
      #not implemented
      return
    
    if(displayState == 15): #WifiStatus
      animationCounter += 1
      if wifi_config.is_wifi_connected():
        message = "CONNECTED TO: " + ssid + " IP: " + wifi_config.get_device_ip()
      else:
        message = "NOT CONNECTED"
      if(animationCounter > (len(message) * 6)+32):
        animationCounter = 0
      led.word(message,32-animationCounter)
    
    if(displayState == 16): #WifiConfig
      animationCounter += 1
      message = "SSID: " + wifiConfigSSID + " PASS: " + hcidPassword
      if(animationCounter > (len(message) * 6)+32):
        animationCounter = 0
      led.word(message,32-animationCounter)
    
    if(displayState == 17): #Minibadges
      if(pwrEnable.value() == 1):
        led.word("ON", int((32-(len("ON")*6))/2))
      else:
        led.word("OFF", int((32-(len("OFF")*6))/2))
    
    if(displayState == 18): #Minibadge Text Message
      animationCounter += 1
      if((len(minibadgeTextMessage) * 6)-1 > 32):
        
        if(animationCounter > (len(minibadgeTextMessage) * 6)+32):
          #animationCounter = 0
          displayState = minibadgePreviousDisplayState #put display back to where it was
        led.word(minibadgeTextMessage,32-animationCounter)
      else:
        if(animationCounter > 26): #(2000/displayUpdateDelay)):
          displayState = minibadgePreviousDisplayState #put display back to where it was
        led.word(minibadgeTextMessage, int((32-(len(minibadgeTextMessage)*6))/2))
    
    if(displayState == 19): #Minibadge Pixel Message
      animationCounter += 1
      if(animationCounter > (pixelDisplayDelay/displayUpdateDelay)):
        displayState = minibadgePreviousDisplayState
      led.set_pixels(pixelDisplayData)
      
    led.update_display()
    if pixelDisplayDelay > 0:
      await asyncio.sleep_ms(pixelDisplayDelay)
    else:
      await asyncio.sleep_ms(displayUpdateDelay)

async def minibadgeComms(): #Handle minibadge I2C communications
  global displayState
  global minibadgeTextMessage
  global minibadgePreviousDisplayState
  global pixelDisplayData
  global pixelDisplayDelay
  
  while(True):
    if displayState != 18 and displayState != 19:
      data = bytearray(1)
      pixelDisplayDelay = 0
      for x in I2CDeviceList:
        try:
          i2c2.start()
          data[0] = x<<1 | 0x1
          i2c2.write(data)
          i2c2.readinto(data, False)
          if data[0] == 1:
            data2 = bytearray(1)
            i2c2.readinto(data2, True) #get button status
          elif data[0] == 2: #Text Message
            i2c2.readinto(data, False) #get message length
            data2 = bytearray(data[0])
            i2c2.readinto(data2, True)
            minibadgePreviousDisplayState = displayState
            minibadgeTextMessage = str(data2)
            txtLength = len(minibadgeTextMessage)
            minibadgeTextMessage = minibadgeTextMessage[12:txtLength-2] #trim to just the message
            displayState = 18 #Minibadge Text Message
          elif data[0] == 3: #Pixel Message
            data2 = bytearray(32)
            i2c2.readinto(data2, True)
            minibadgePreviousDisplayState = displayState
            for x in range(32):
              pixelDisplayData[x] = data2[x]
            pixelDisplayDelay = 2000 #2 seconds
            displayState = 19 #Minibadge Pixel Message
          elif data[0] == 4: #Pixel Message with display time
            i2c2.readinto(data, False) #get display time
            pixelDisplayDelay = data[0] * 10
            data2 = bytearray(32)
            i2c2.readinto(data2, True)
            minibadgePreviousDisplayState = displayState
            for x in range(32):
              pixelDisplayData[x] = data2[x]
            displayState = 19 #Minibadge Pixel Message
          elif data[0] == 5: #Custom Message
            i2c2.readinto(data, False) #get message length
            data2 = bytearray(data[0])
            i2c2.readinto(data2, True)
          else:
            i2c2.readinto(data, True)
          i2c2.stop()
        except Exception as e:
          print(e)
        await asyncio.sleep_ms(1)
    if pixelDisplayDelay > 0:
      await asyncio.sleep_ms(pixelDisplayDelay)
    else:
      await asyncio.sleep_ms(100)
      
async def updateHCScore():
  while(True):
    userHCScore = hc.get_score(hcid)
    if userHCScore == "Error":
      userHCScore = "0"
    
    data = bytearray(4)
    for x in I2CDeviceList: #Send HC score to minibadges
      if x != 0x01:
        try:
          i2c2.start()
          data[0] = x<<1 
          data[1] = 0x01
          data[2] = userHCScore >> 8
          data[3] = userHCScore
          i2c2.write(data)
          i2c2.stop()
        except:
          pass
    
    await asyncio.sleep(60)

upBtn = Pushbutton(upPin)
downBtn = Pushbutton(downPin)
selectBtn = Pushbutton(selectPin)

upBtn.press_func(buttonPressed, (1,))
downBtn.press_func(buttonPressed, (2,))
selectBtn.press_func(buttonPressed, (3,))
upBtn.debounce_ms = 100


def startWifi():
  global userHCScore
  wifi_config.start_wifi()
  
  if wifi_config.is_wifi_connected():
    userHCScore = hc.get_score(hcid)
    if userHCScore == "Error":
      userHCScore = "0"
    print("-- H -- A -- C -- K -- E -- R -- M -- A -- N --")
    print("Hacker Score: " + str(userHCScore))
    print("Generated HCID: " + hcid)
    print("-- H -- A -- C -- K -- E -- R -- M -- A -- N --")

  
def configureWifi():
    authmode = 4 # wpa2
    configure.start_wifi_config(wifiConfigSSID, hcidPassword, authmode)
    wifi_config.start_wifi()
    

def start_loop():
  loop = asyncio.get_event_loop()
  loop.call_soon(updateDisplay())
  loop.call_soon(minibadgeComms())
  loop.call_soon(updateHCScore())
  loop.run_forever()

_thread.start_new_thread(start_loop, ())

startWifi()

while 1:
  if wifiConfigMode == 1:
      configureWifi()
      wifiConfigMode = 0
      displayState = 9

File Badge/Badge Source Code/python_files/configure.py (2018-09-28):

import network
from microWebSrv import MicroWebSrv
import ujson
import wifi_config
import time
import hcid

web_dir = "www/"
wifi_config_file = "wifi.json"
default_ssid = "BadgeHerd"
default_password = "SECRETPASSWORD"
default_custom_message = ""
hcid = hcid.getHCID()

def letswait(seconds):
  count = 0
  while count <= seconds:
    time.sleep(1) # this sleep sucks
    print(".", end='')
    count = count + 1

def _acceptWebSocketCallback(webSocket, httpClient) :
 print("WS ACCEPT")
 webSocket.RecvTextCallback   = _recvTextCallback
 webSocket.RecvBinaryCallback = _recvBinaryCallback
 webSocket.ClosedCallback 	 = _closedCallback

def _recvTextCallback(webSocket, msg) :
 print("WS RECV TEXT : %s" % msg)
 webSocket.SendText("Reply for %s" % msg)

def _recvBinaryCallback(webSocket, data) :
 print("WS RECV DATA : %s" % data)

def _closedCallback(webSocket) :
 print("WS CLOSED")

# ----------------------------------------------------------------------------

@MicroWebSrv.route('/', 'GET')
def _httpHandlerFinish(httpClient, httpResponse) :
  
  try:
    print("1")
    config = wifi_config.readConfig(wifi_config_file)
    ssid = config["ssid"]
    password = config["password"]
    custom_message = config["custom_message"]
  except OSError:
    print("2")
    ssid = default_ssid
    password = default_password
    custom_message = default_custom_message
    
  print("3")
  f = open( web_dir + 'index_1.html', 'r')
  page = str(f.read())
  f.close()
  print("4")
  page = page + """<table style="margin-left: auto; margin-right: auto;"><tbody><tr><td>SSIDs:</td><td><input name="ssid" type="text" value="%s" /></td></tr><tr><td>Wifi Password:</td><td><input name="password" type="password" value="%s" /></td></tr><tr><td></td><td><input type="button" class="button" value="Reset Wifi Settings" Onclick="window.location.href='/reset'"></td></tr><tr><td><h1 style="text-align: center;"><span style="color: #f90;">Other Settings</span></h1></td></tr><tr><td>Hacker's Challenge ID:</td><td>%s</td></tr><tr><td>Custom Message:</td><td><input name="custom_message" maxlength="250" type="text" value="%s" /></td></tr></tbody></table>""" % ( MicroWebSrv.HTMLEscape(ssid), MicroWebSrv.HTMLEscape(password), MicroWebSrv.HTMLEscape(hcid), MicroWebSrv.HTMLEscape(custom_message) )f = open( web_dir + 'index_2.html', 'r')
  page = page + str(f.read())
  f.close()
  print("5")

  httpResponse.WriteResponseOk( headers         = None,
                                contentType     = "text/html",
                                contentCharset  = "UTF-8",
                                content         = page )
  print("User hit the Main Page.")
  
@MicroWebSrv.route('/reset', 'GET')
def _httpHandlerFinish(httpClient, httpResponse) :
  f = open( web_dir + 'config_1.html', 'r')
  content = str(f.read())
  f.close()
  
  content += str("Reset Wifi Settings to Default")
  
  f = open( web_dir + 'config_2.html', 'r')
  content += str(f.read())
  f.close()

  httpResponse.WriteResponseOk( headers         = None,
                                contentType     = "text/html",
                                contentCharset  = "UTF-8",
                                content         = content )
  print("User hit the RESET Page.")
  try:
    config = wifi_config.readConfig(wifi_config_file)
    custom_message = config["custom_message"]
  except OSError:
    custom_message = default_custom_message
  config_data = {'ssid': MicroWebSrv.HTMLEscape(default_ssid), 'password': MicroWebSrv.HTMLEscape(default_password), 'custom_message': MicroWebSrv.HTMLEscape(custom_message)}
  
  f = open(wifi_config_file, "w")
  json = ujson.dumps(config_data)
  f.write(json)
  f.close()

@MicroWebSrv.route('/configure', 'POST')
def _httpHandlerConfigurePost(httpClient, httpResponse) :
  formData  = httpClient.ReadRequestPostedFormData()
  ssid  = formData["ssid"]
  password  = formData["password"]
  custom_message = formData["custom_message"]
  f = open( web_dir + 'config_1.html', 'r')
  content = str(f.read())
  f.close()
  
  config_data = {'ssid': MicroWebSrv.HTMLEscape(ssid), 'password': MicroWebSrv.HTMLEscape(password), 'custom_message': MicroWebSrv.HTMLEscape(custom_message)}

  content += str(config_data)
  
  f = open( web_dir + 'config_2.html', 'r')
  content += str(f.read())
  f.close()
  
  httpResponse.WriteResponseOk( headers         = None,
                                contentType     = "text/html",
                                contentCharset  = "UTF-8",
                                content         =  content)

  f = open(wifi_config_file, "w")
  json = ujson.dumps(config_data)
  f.write(json)
  f.close()
  print("User POSTED settings to /configure")
  print("Wrote the following to " + wifi_config_file + "\n" + json)

@MicroWebSrv.route('/finish', 'GET')
def _httpHandlerFinish(httpClient, httpResponse) :
  file = open( web_dir + 'end.html', 'r')
  page = str(file.read())
  file.close()
  print("1")
  httpResponse.WriteResponseOk( headers         = None,
                                contentType     = "text/html",
                                contentCharset  = "UTF-8",
                                content         = page )
  print("User hit the Finished button. Closing down WebServer & AP.")
  stop_ap()
  stop_webserver()

def start_ap(essid_name, ap_password, authmode_setting):
  ap.active(True)
  ap.config(essid=essid_name, password=ap_password, authmode=authmode_setting)
  print("Badge SSID: '{:s}'".format(essid_name)) # It would be good to show this on the badge screen.
  print("Badge Wifi Password: {:s}".format(ap_password))

def stop_ap():
  print("Stopping AP", end='')
  letswait(5)
  print()
  ap.active(False)
  print("--- Stopped AP ---")
  
def stop_webserver():
  srv.Stop()
  print("--- Stopped WebServer ---")
  
def start_wifi_config(essid_name, ap_password, authmode_setting):
  print()
  print("====================== Start Wifi Config ======================")
  print()
  letswait(3)
  start_ap(essid_name, ap_password, authmode_setting)
  # Start WebServer
  ip = ap.ifconfig()[0]
  print("Web Server: Listening http://{}:80/".format(ip))  # It would be good to show this on the badge screen.
  srv.Start(threaded=False);

# ----------------------------------------------------------------------------

def main():
  start_wifi_config("Saintcon Badge")
  
ap = network.WLAN(network.AP_IF)
sta = network.WLAN(network.STA_IF)
ip = "No IP Set"

# Setup Webserver (does not start it)
srv = MicroWebSrv(webPath=web_dir)
srv.MaxWebSocketRecvLen     = 256
srv.WebSocketThreaded = False
srv.AcceptWebSocketCallback = _acceptWebSocketCallback
